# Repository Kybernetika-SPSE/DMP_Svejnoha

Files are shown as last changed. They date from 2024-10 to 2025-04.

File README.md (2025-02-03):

# Stanice pro monitorování okolního prostředí

## Zadání
Cílem projektu je navrhnout a následně vyrobit stanici složenou z LED displeje a senzorů, které budou sledovat vybrané parametry okolního prostředí. Zařízení bude obsahovat multifunkční displej a na základě uživatelských pokynů zobrazovat data. 

## Vedoucí práce
Jiří Švihla

## Harmonogram práce
- [x]   Zhotovení zadání MP (23. 9.)
- [/zadání maturitní práce/](zadani/DMP_zadani_SVEJNOHA.pdf)
- [x]   Výběr potřebných komponentů, seznámení se s problematikou a možnostmi programování LED
displeje (31. 10.)
- [/dílčí vypracování říjen/](dilci_vypracovani/SVEJNOHA_RIJEN.pdf)
- [x]   Návrh a realizace estetického a funkčního designu zařízení (28. 11.)
- [x]   Hardwarového zapojení senzorů a napájení (19. 12.)
- [/dílčí vypracování prosinec+listopad/](dilci_vypracovani/SVEJNOHA_LISTOPAD_A_PROSINEC.pdf)
- [x]   Programování displeje, zajištění možností využití zobrazení dat a ornamentů na displeji (30. 1.)
- [/dílčí vypracování leden/](dilci_vypracovani/SVEJNOHA_LEDEN.pdf)
- [ ]   Kompletace zařízení a testování (27. 2.)
- [ ]   Zpracování dokumentace (24. 3.)

## Termín odevzdání
31. března 2025

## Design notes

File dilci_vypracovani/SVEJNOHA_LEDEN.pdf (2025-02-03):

## MAREK ŠVEJNOHA – DÍLČÍ VYPRACOVÁNÍ – LEDEN

V lednu již dorazila vyrobená deska plošných spojů, ihned jsem začal s naletováním všech senzorů a konektorů na PCB aby mohlo co nejdříve dojít k programování.

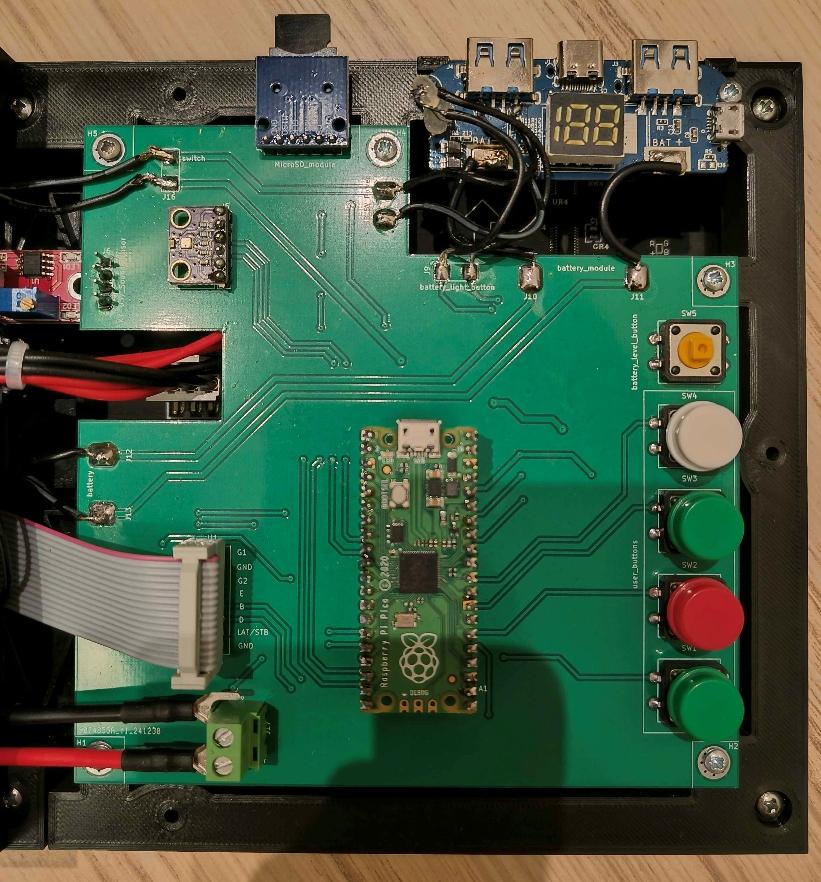
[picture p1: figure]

Postupně došlo k tisknutí dalších částí na 3D tiskárně.

V současné době dochází k programování. Zde přikládám návrh, jak bude již naprogramovaný displej vypadat:

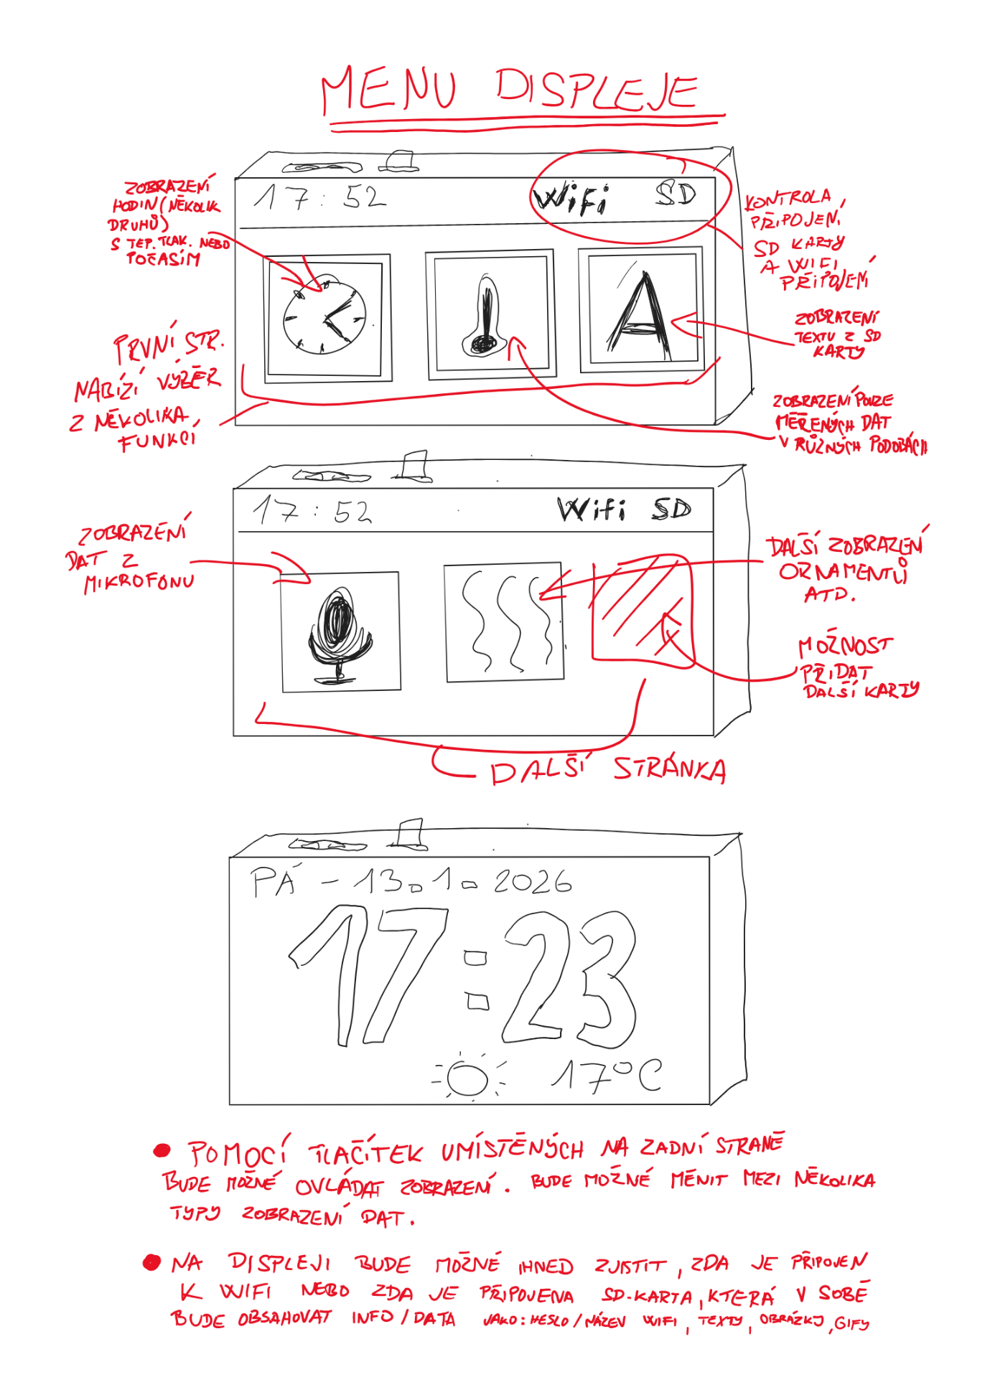
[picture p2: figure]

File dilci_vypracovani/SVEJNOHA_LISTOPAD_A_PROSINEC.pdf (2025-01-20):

MAREK ŠVEJNOHA – DÍLČÍ VYPRACOVÁNÍ – PROSINEC

Za prosincové období byl vypracován návrh desky plošných spojů (viz obrázek 1) v programu KiCad. Toto PCB bude obsluhovat displej. Je zde prostor pro mikrokontroler Raspberry pi Pico W, tlačítka nebo konektory. Bylo vypracováno hned několik nových footprintů a symbolů, které v knihovnách KiCadu nejsou, ale jsou pro tuto práci důležité. Například pro konektor HUB75 nebo pro konektorové lišty pro připojení senzorů. HUB75 je v návrhu připojen k Picu.

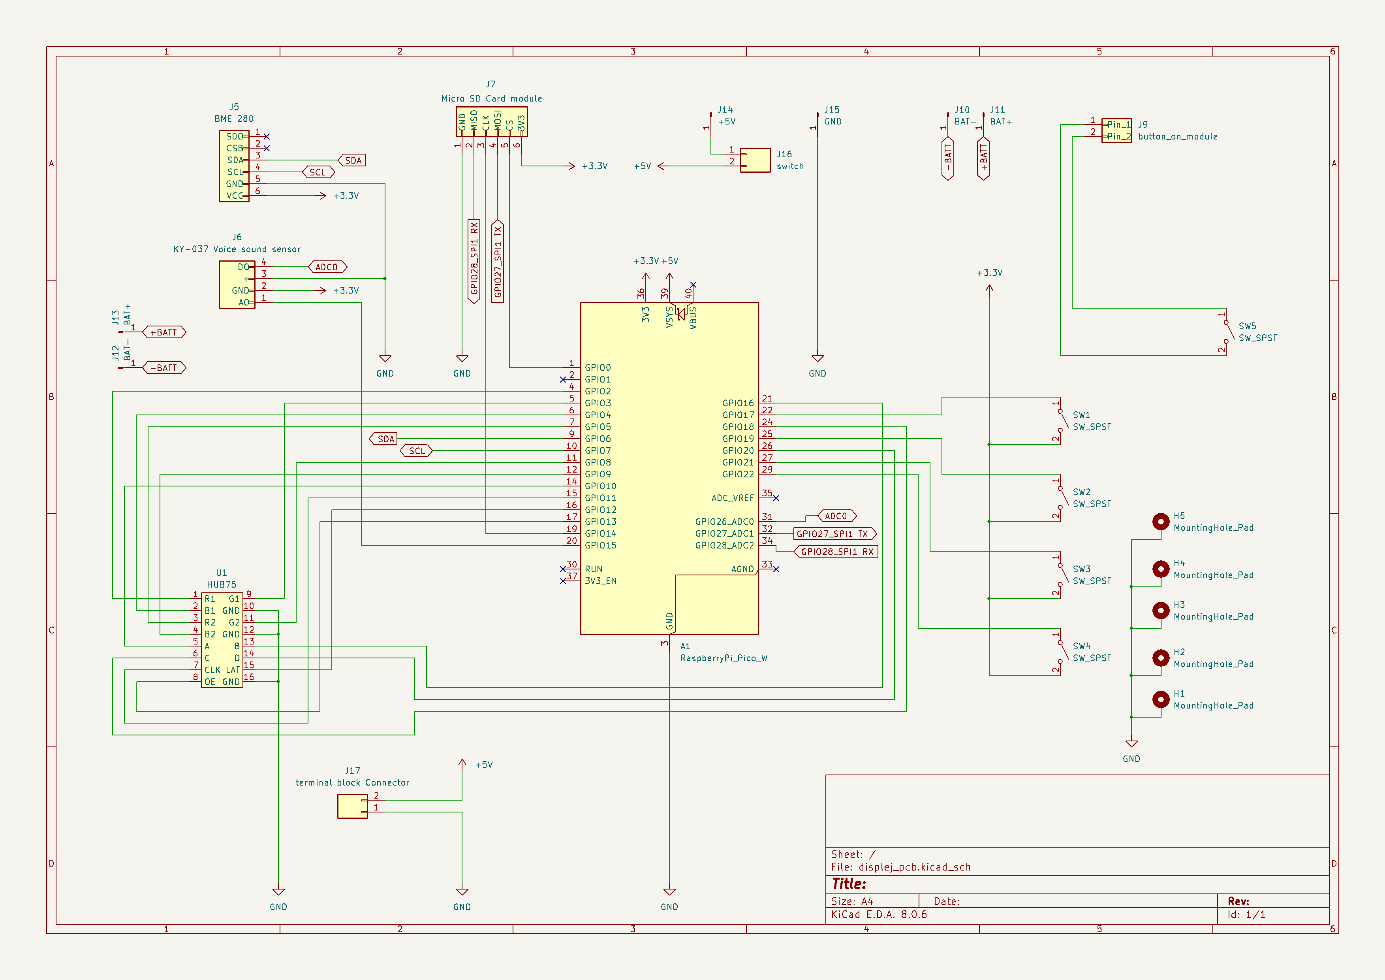
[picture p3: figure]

Obrázek 1

Napájení bude zajištěno pomocí nabíjecího modulu, který jsem získal z powerbanky, ten bude umístěn v pravém horním rohu, kde je pro něj připraven výřez (viz obrázek 2). Z modulu povedou kabely na desku. Za prvé to bude 5V napájení, které bude přivedeno z USB portu. Za druhé přívod k akumulátoru, který bude na druhé půlce displeje a za třetí bude vyvedené tlačítko pro ověření nabití baterie.

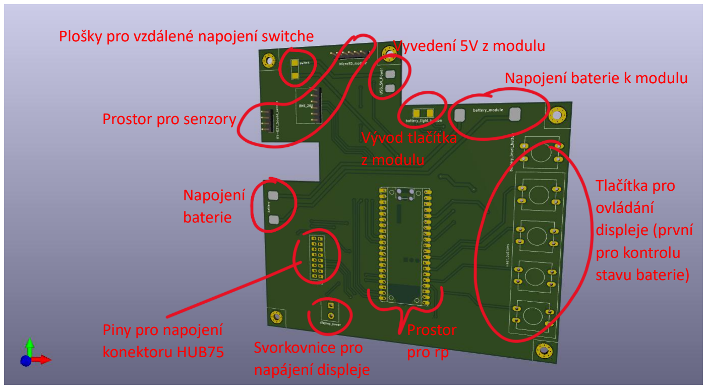
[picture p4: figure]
Napojení baterie k modulu; Vyvedení 5V z modulu; Vývod tlačítka z modulu; Napojení baterie; Plošky pro vzdálené napojení switche; Prostor pro senzory; Tlačítka pro ovládání displeje (první pro kontrolu stavu baterie); Prostor pro rp; Piny pro napojení; konektoru HUB75; Svorkovnice pro; napájení displeje

Vyvedených 5V pokračuje do hlavního spínače, které bude umístěno mimo PCB. To zajistí odpojení a připojení napájení k Picu a displeji. PCB obsahuje také 4 tlačítka pro ovládání displeje. Nakonec jsou zde díry pro uchycení k obalu displeje. Zbytek částí popsáno na obrázku (viz obrázek 2).

Obrázek 2

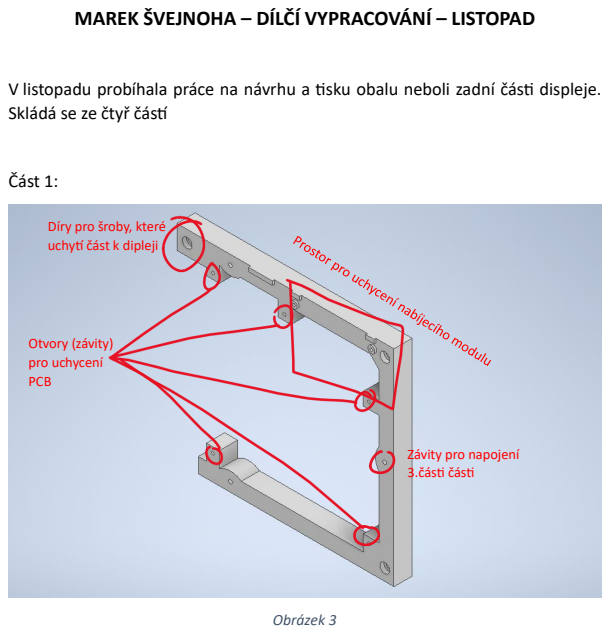
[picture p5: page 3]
Část 1:; Obrázek 3; Otvory (závity) pro uchycení PCB

MAREK ŠVEJNOHA – DÍLČÍ VYPRACOVÁNÍ – LISTOPAD

V listopadu probíhala práce na návrhu a tisku obalu neboli zadní části displeje.
Skládá se ze čtyř částí

Díry pro šroby, které
uchytí část k dipleji

Závity pro napojení
3.části části

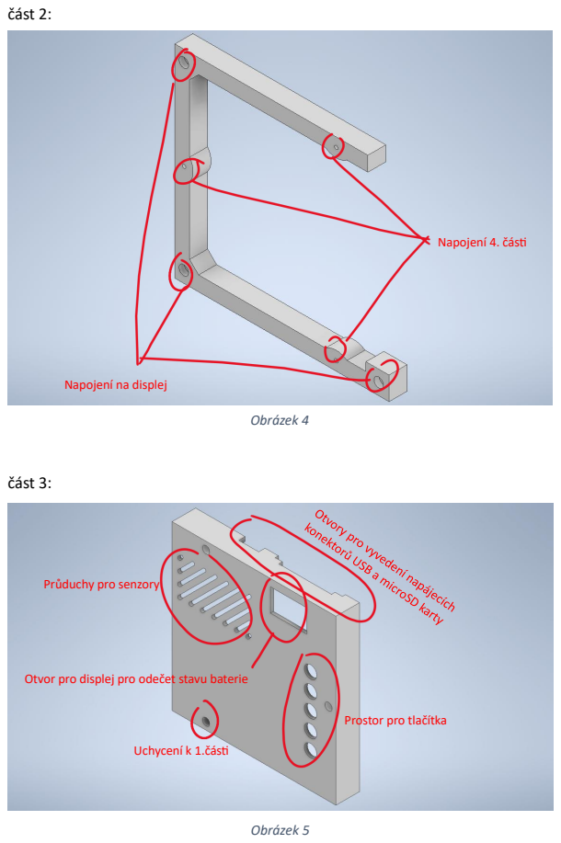
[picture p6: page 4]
část 2:; část 3:; Obrázek 5; Napojení 4. části; Uchycení k 1.části; Obrázek 4

Napojení na displej

Průduchy pro senzory

Otvor pro displej pro odečet stavu baterie

Prostor pro tlačítka

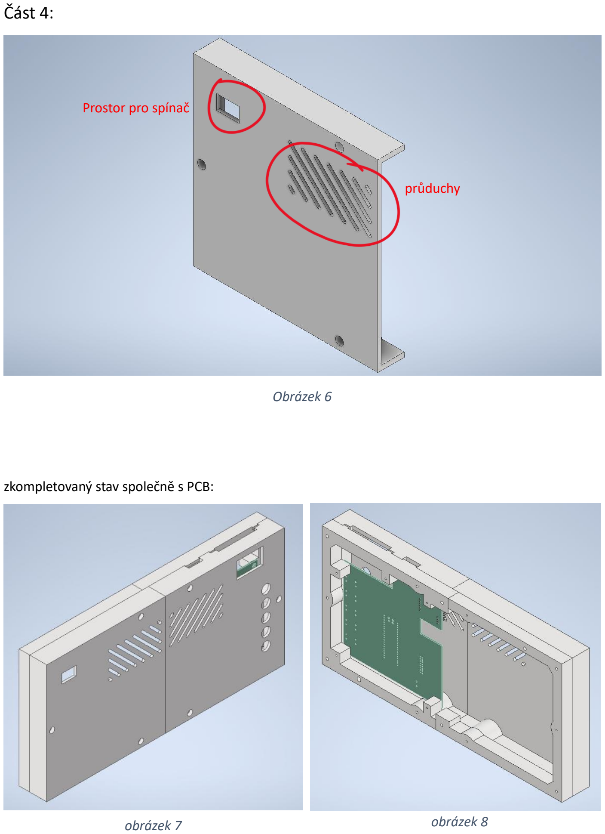
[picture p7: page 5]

Část 4:

Obrázek 6

zkompletovaný stav společně s PCB:

obrázek 7

obrázek 8

průduchy

Prostor pro spínač

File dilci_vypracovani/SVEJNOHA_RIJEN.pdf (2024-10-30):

MAREK ŠVEJNOHA – DÍLČÍ VYPRACOVÁNÍ – ŘÍJEN

V průběhu října jsem vybral komponenty, které jsou potřeba pro úspěšné sestavení výrobku. V první řadě byl objednán (23. října, 2024) Waveshare RGB plnobarevný LED maticový displej, 64 x 32 pixelů, který je ze všeho nejvíce důležitý. Displej podporuje ovládání pomocí Arduina, ESP32, Raspberry Pi nebo Raspberry Pi Pico, které pro ovládání využiji já. Displej vyžaduje samostatný napájecí zdroj 5 V/2,5 A. Použiji akumulátory a napájecí modul, což zajistí, že stanice bude jednoduše přemisťovatelná. Displej využívá rozhraní HUB75, které umožňuje ovládání přímo z řídící jednotky (Raspberry Pi Pico). Mimo jiné zahrnuje piny pro:

- Data: Přenos dat pro jednotlivé barvy (červená, zelená, modrá).
- Hodiny: Synchronizace přenosu dat.
- Latch: Ukládání dat do registrů.
- Enable: Povolení nebo zakázání displeje.
- Řádky: Výběr konkrétního řádku na displeji.

Jakmile displej dorazí, pustím se do programování a zapojení obvodu. Pro programování displeje je volně dostupná knihovna rpi-rgb-led-matrix. Tato knihovna je určena pro Raspberry Pi a umožňuje ovládání různých LED maticových displejů přes rozhraní HUB75. Je možné ji najít na GitHubu. Byl také zakoupen senzor DHT11 pro měření teploty a vlhkosti vzduchu a také zvukový senzor s analogovým výstupem, který využiji pro zobrazení zvuku na displeji. Další senzory budou popřípadě v budoucnu dokoupeny.

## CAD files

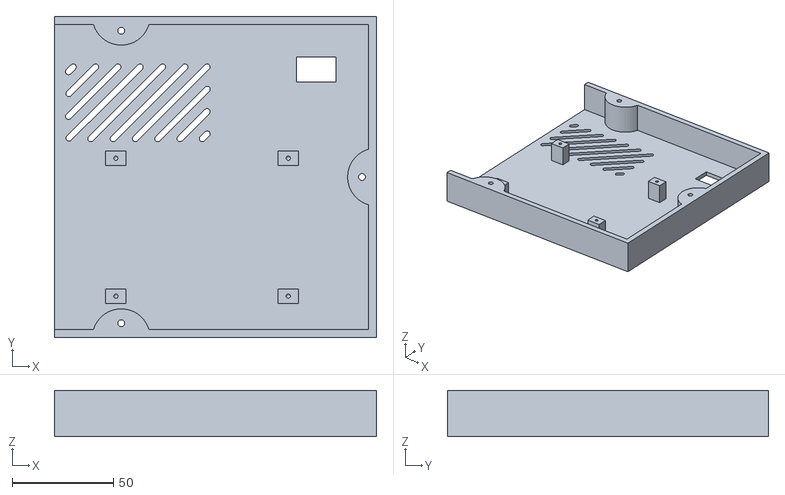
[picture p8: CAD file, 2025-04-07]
3D_modely/stl/display_cover_part2_back.stl
158.8 x 158.5 x 22.8

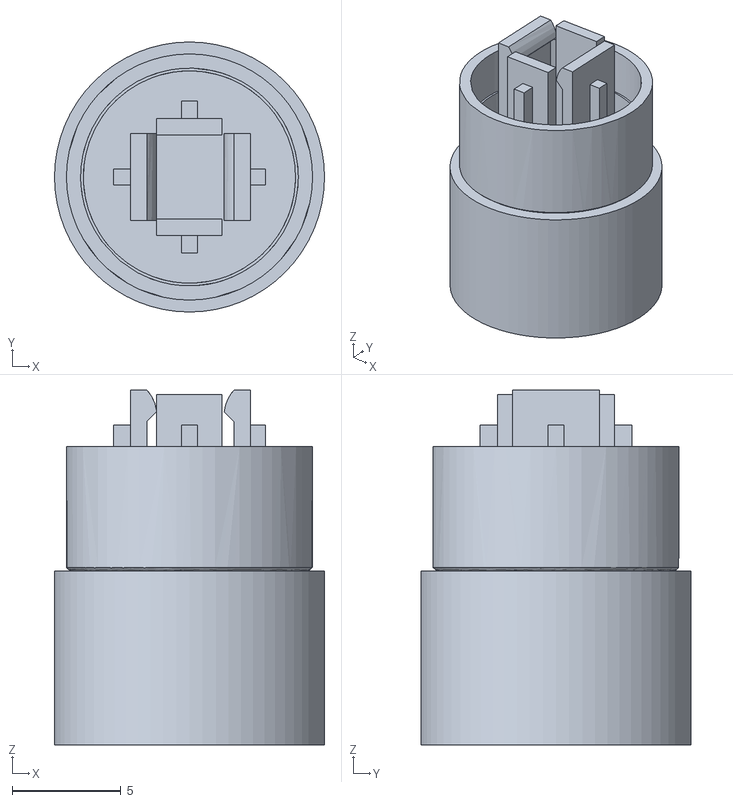
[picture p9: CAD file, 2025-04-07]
3D_modely/stl/setting_buttons.stl
12.4 x 12.4 x 16.3

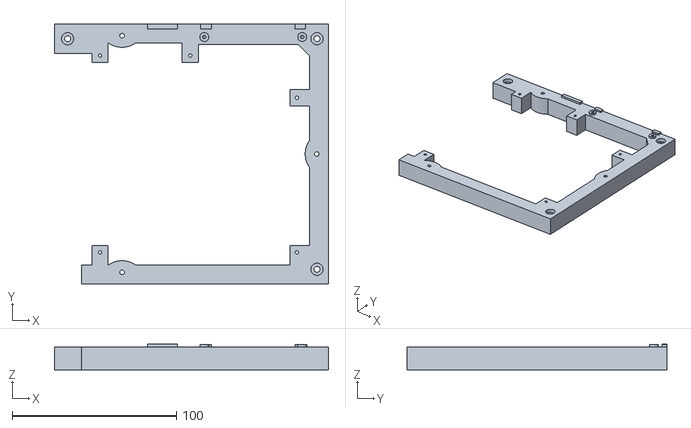
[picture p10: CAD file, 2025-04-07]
3D_modely/stl/display_cover_part1.stl
167.0 x 158.5 x 15.6

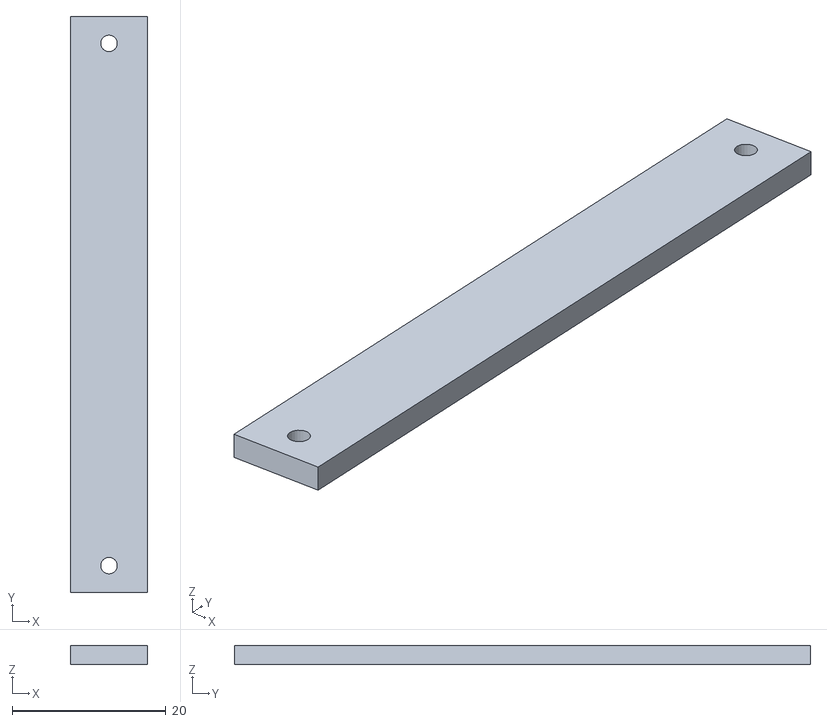
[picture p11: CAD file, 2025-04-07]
3D_modely/stl/battery_plate.stl
10.0 x 75.0 x 2.50

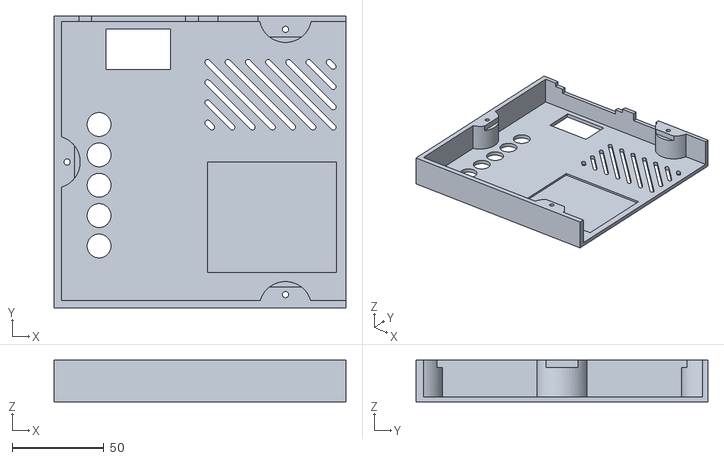
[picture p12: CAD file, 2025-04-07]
3D_modely/stl/display_cover_part1_back.stl
158.8 x 158.5 x 22.8

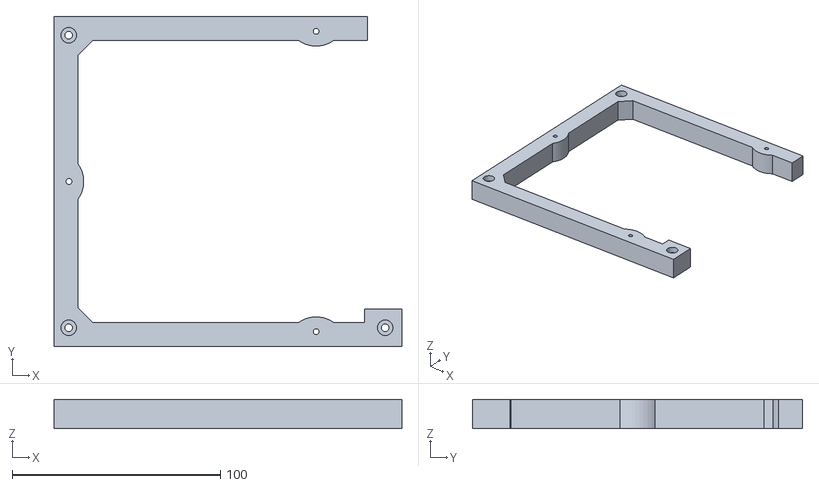
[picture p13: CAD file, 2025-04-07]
3D_modely/stl/display_cover_part2.stl
167.0 x 158.5 x 14.0

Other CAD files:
3D_modely/Sestava_kryt_na_displej_PCB.iam
3D_modely/battery_plate.ipt
3D_modely/button_plate_arrow.ipt
3D_modely/button_plate_battery.ipt
3D_modely/button_plate_brightness.ipt
3D_modely/button_plate_cross.ipt
3D_modely/display_cover_part1.ipt
3D_modely/display_cover_part1_back.ipt
3D_modely/display_cover_part2.ipt
3D_modely/display_cover_part2_back.ipt

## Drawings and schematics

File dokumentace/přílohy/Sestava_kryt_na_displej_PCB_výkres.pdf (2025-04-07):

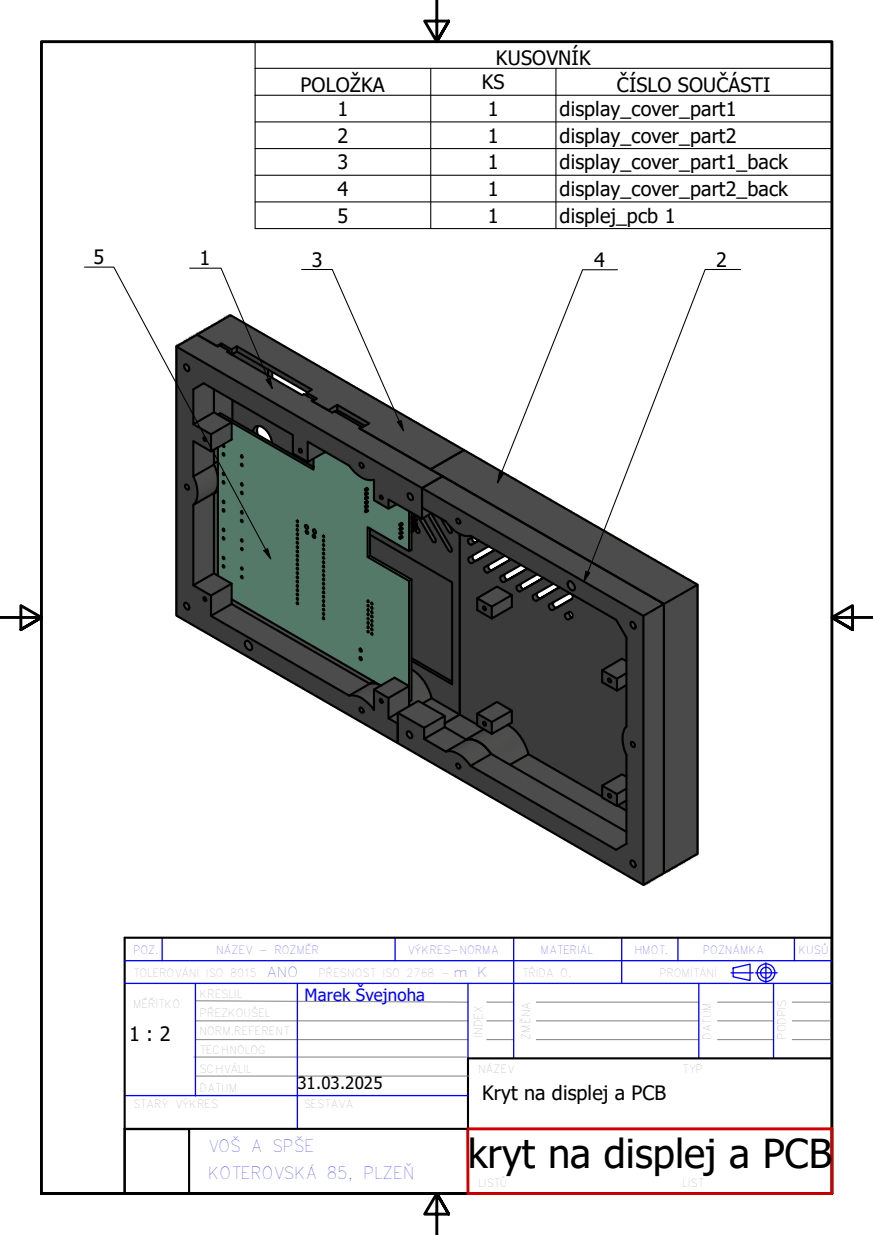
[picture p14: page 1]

KUSOVNÍK

POLOŽKA | KS | ČÍSLO SOUČÁSTI
1 | 1 | display_cover_part1
2 | 1 | display_cover_part2
3 | 1 | display_cover_part1_back
4 | 1 | display_cover_part2_back
5 | 1 | displej_pcb 1

POZ. | NÁZEV - ROZMĚR | VÝKRES-NORMA | MATERIÁL | HMOT. | POZNÁMKA | KUSŮ

TOLEROVÁNÍ ISO 8015 ANO PŘESNOST ISO 2768 -m K | TŘÍDA O. | PROMÍTÁNÍ
MĚŘÍTKO 1 : 2 | KRESLIL | Marek Švejnoha

PŘEZKOUŠEL

NORM.REFERENT
TECHNOLOG
SCHVÁLIL | | NÁZEV TYP Kryt na displej a PCB
DATUM | 31.03.2025

STARÝ VÝKRES | | SESTAVA

VOŠ A SPŠE KOTEROVSKÁ 85, PLZEŇ | kryt na displej a PCB LISTŮ LIST

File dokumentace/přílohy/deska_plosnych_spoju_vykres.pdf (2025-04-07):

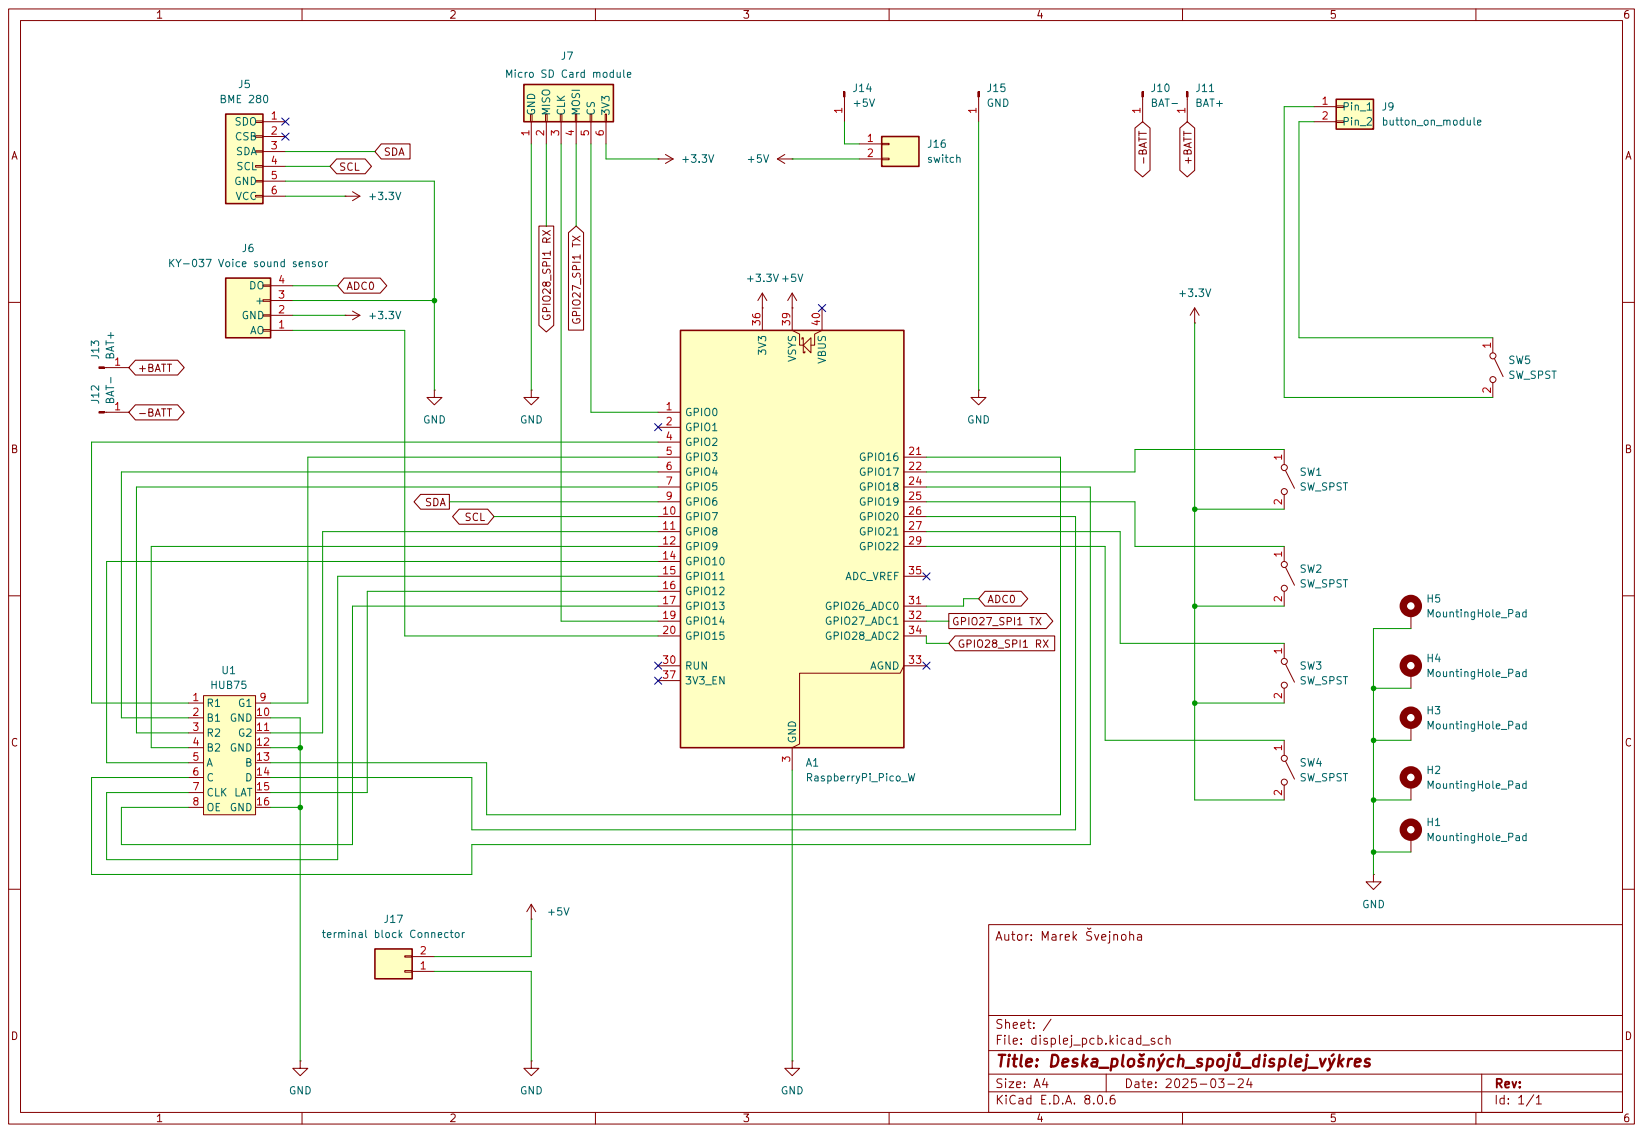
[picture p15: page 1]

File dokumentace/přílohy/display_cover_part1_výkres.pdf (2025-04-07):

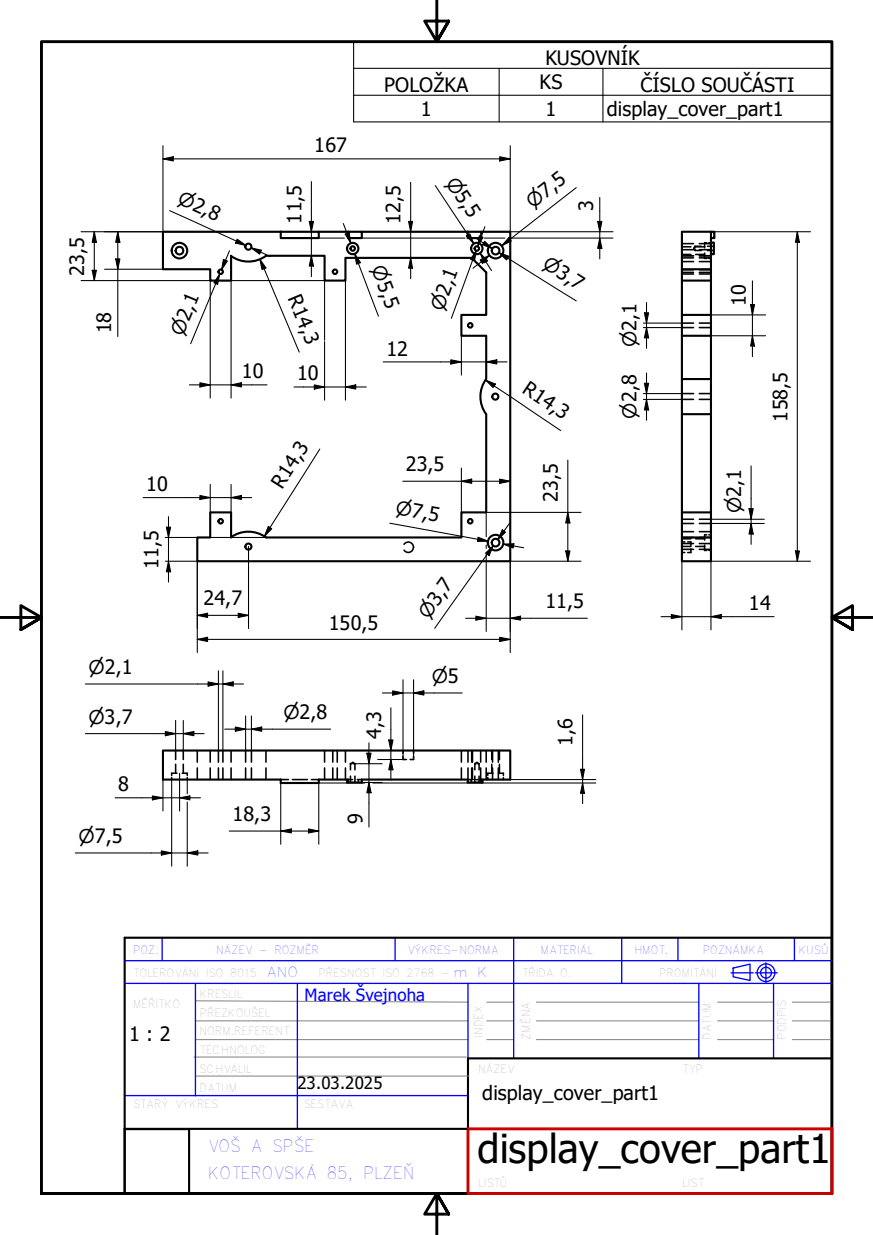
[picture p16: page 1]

KUSOVNÍK

POLOŽKA | KS | ČÍSLO SOUČÁSTI
1 | 1 | display_cover_part1

POZ. | NÁZEV - ROZMĚR | VÝKRES-NORMA | MATERIÁL | HMOT. | POZNÁMKA | KUSŮ

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

PŘEZKOUŠEL

NORM.REFERENT
TECHNOLOG
SCHVÁLIL | | NÁZEV TYP display_cover_part1
DATUM | 23.03.2025

STARÝ VÝKRES | | SESTAVA

VOŠ A SPŠE KOTEROVSKÁ 85, PLZEŇ | display_cover_part1 LISTŮ LIST

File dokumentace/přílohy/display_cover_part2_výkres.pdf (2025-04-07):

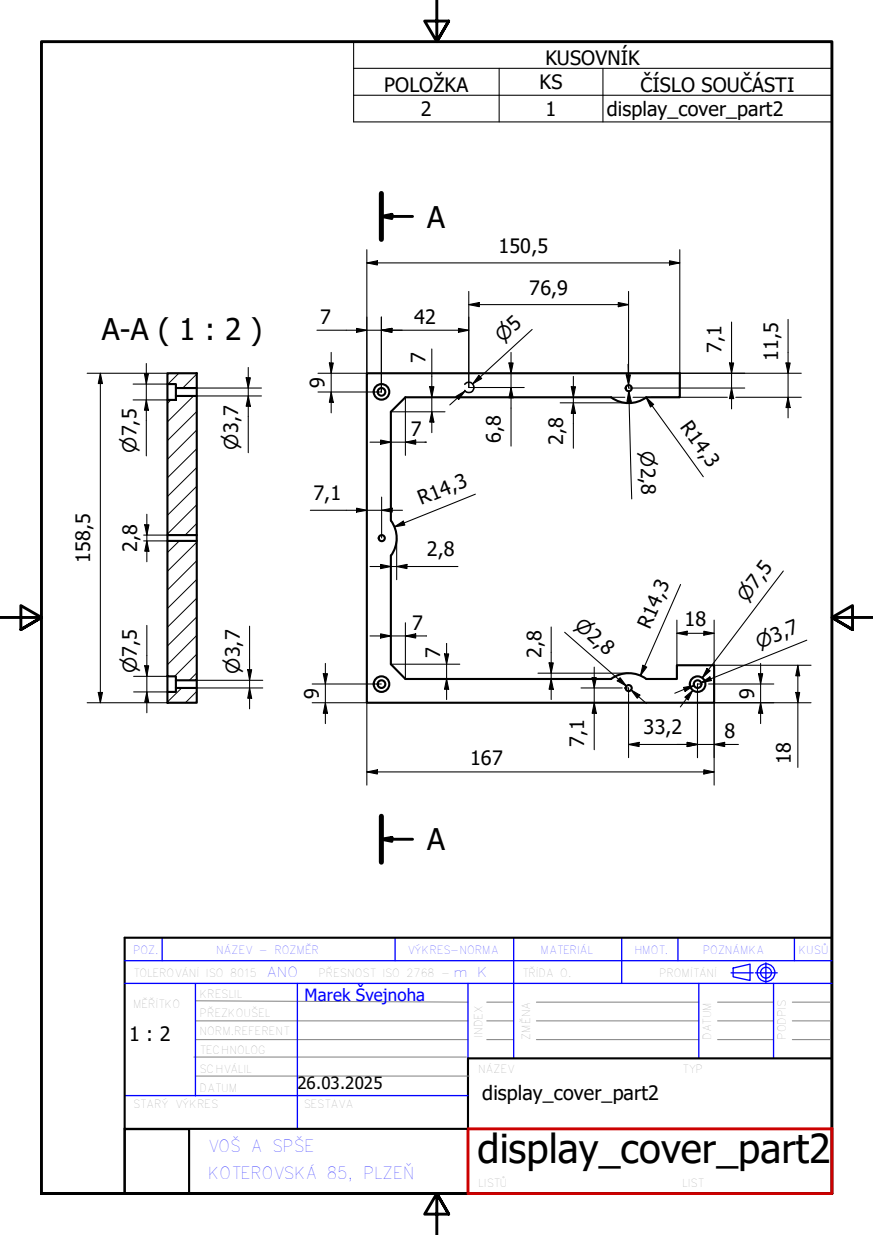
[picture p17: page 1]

KUSOVNÍK

POLOŽKA | KS | ČÍSLO SOUČÁSTI
2 | 1 | display_cover_part2

POZ. | NÁZEV - ROZMĚR | VÝKRES-NORMA | MATERIÁL | HMOT. | POZNÁMKA | KUSŮ

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

PŘEZKOUŠEL

NORM.REFERENT
TECHNOLOG
SCHVÁLIL | | NÁZEV TYP display_cover_part2
DATUM | 26.03.2025

STARÝ VÝKRES | | SESTAVA

VOŠ A SPŠE KOTEROVSKÁ 85, PLZEŇ | display_cover_part2 LISTŮ LIST

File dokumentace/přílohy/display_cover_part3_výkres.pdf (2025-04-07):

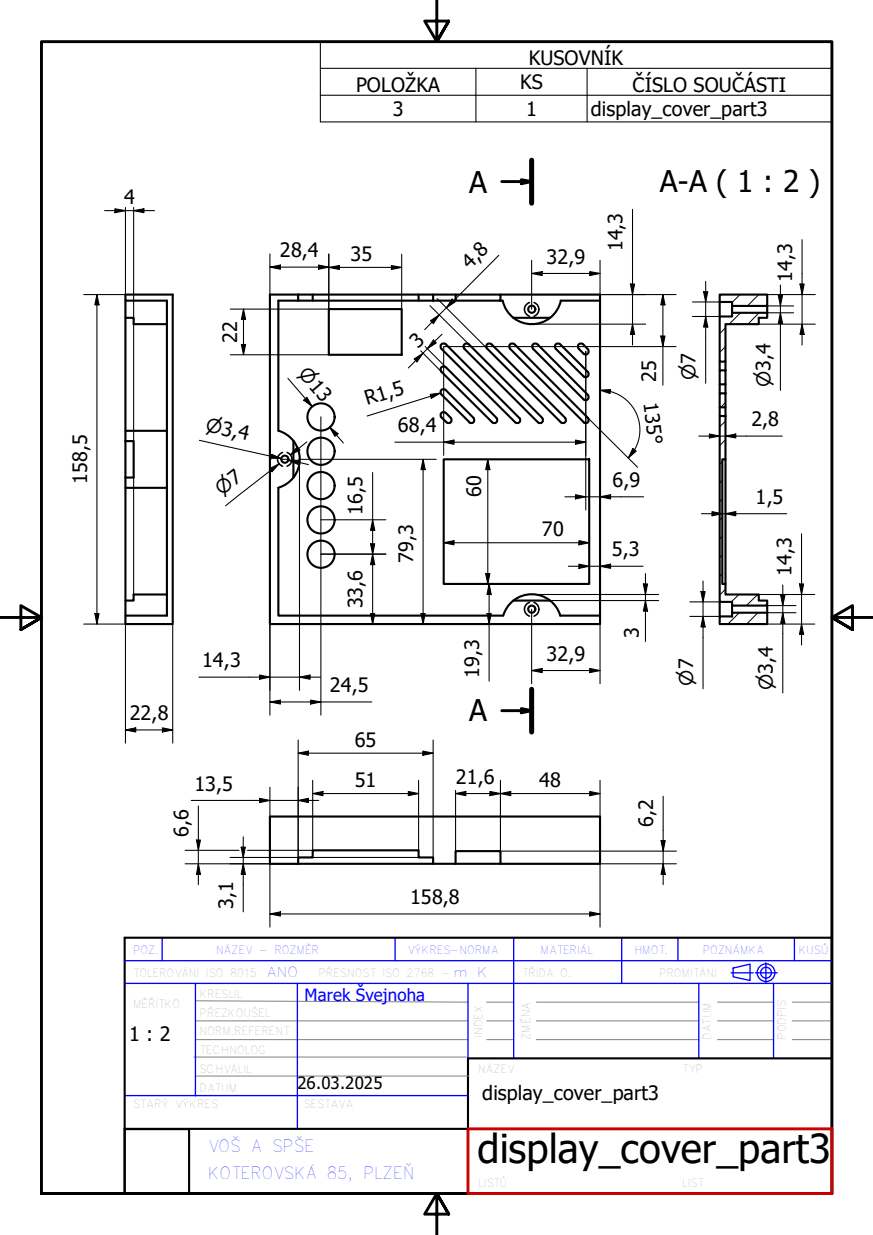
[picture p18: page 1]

KUSOVNÍK

POLOŽKA | KS | ČÍSLO SOUČÁSTI
3 | 1 | display_cover_part3

POZ. | NÁZEV - ROZMĚR | VÝKRES-NORMA | MATERIÁL | HMOT. | POZNÁMKA | KUSŮ

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

PŘEZKOUŠEL

NORM.REFERENT
TECHNOLOG
SCHVÁLIL | | NÁZEV TYP display_cover_part3
DATUM | 26.03.2025

STARÝ VÝKRES | | SESTAVA

VOŠ A SPŠE KOTEROVSKÁ 85, PLZEŇ | display_cover_part3 LISTŮ LIST

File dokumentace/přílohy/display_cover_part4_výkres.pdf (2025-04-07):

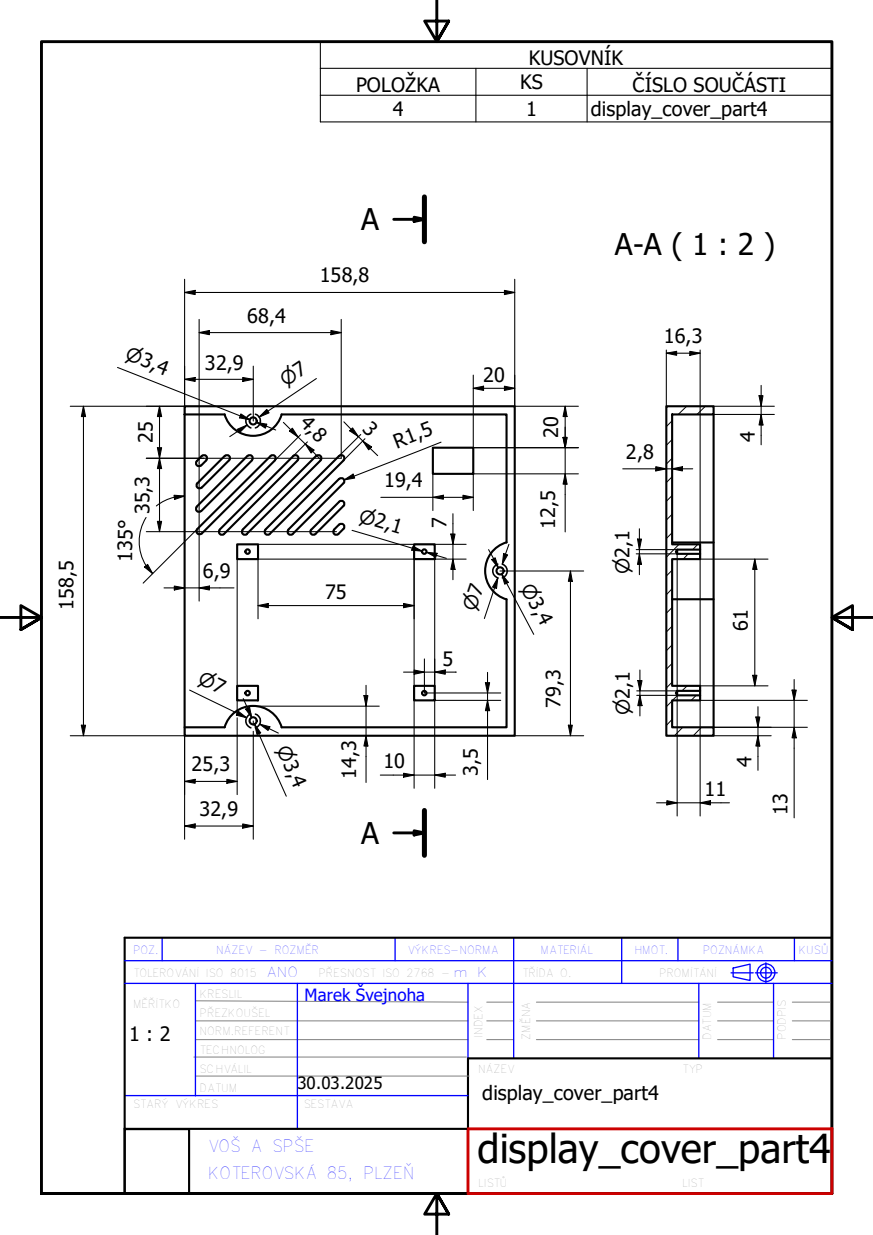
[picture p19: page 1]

KUSOVNÍK

POLOŽKA | KS | ČÍSLO SOUČÁSTI
4 | 1 | display_cover_part4

POZ. | NÁZEV - ROZMĚR | VÝKRES-NORMA | MATERIÁL | HMOT. | POZNÁMKA | KUSŮ

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

PŘEZKOUŠEL

NORM.REFERENT
TECHNOLOG
SCHVÁLIL | | NÁZEV TYP display_cover_part4
DATUM | 30.03.2025

STARÝ VÝKRES | | SESTAVA

VOŠ A SPŠE KOTEROVSKÁ 85, PLZEŇ | display_cover_part4 LISTŮ LIST

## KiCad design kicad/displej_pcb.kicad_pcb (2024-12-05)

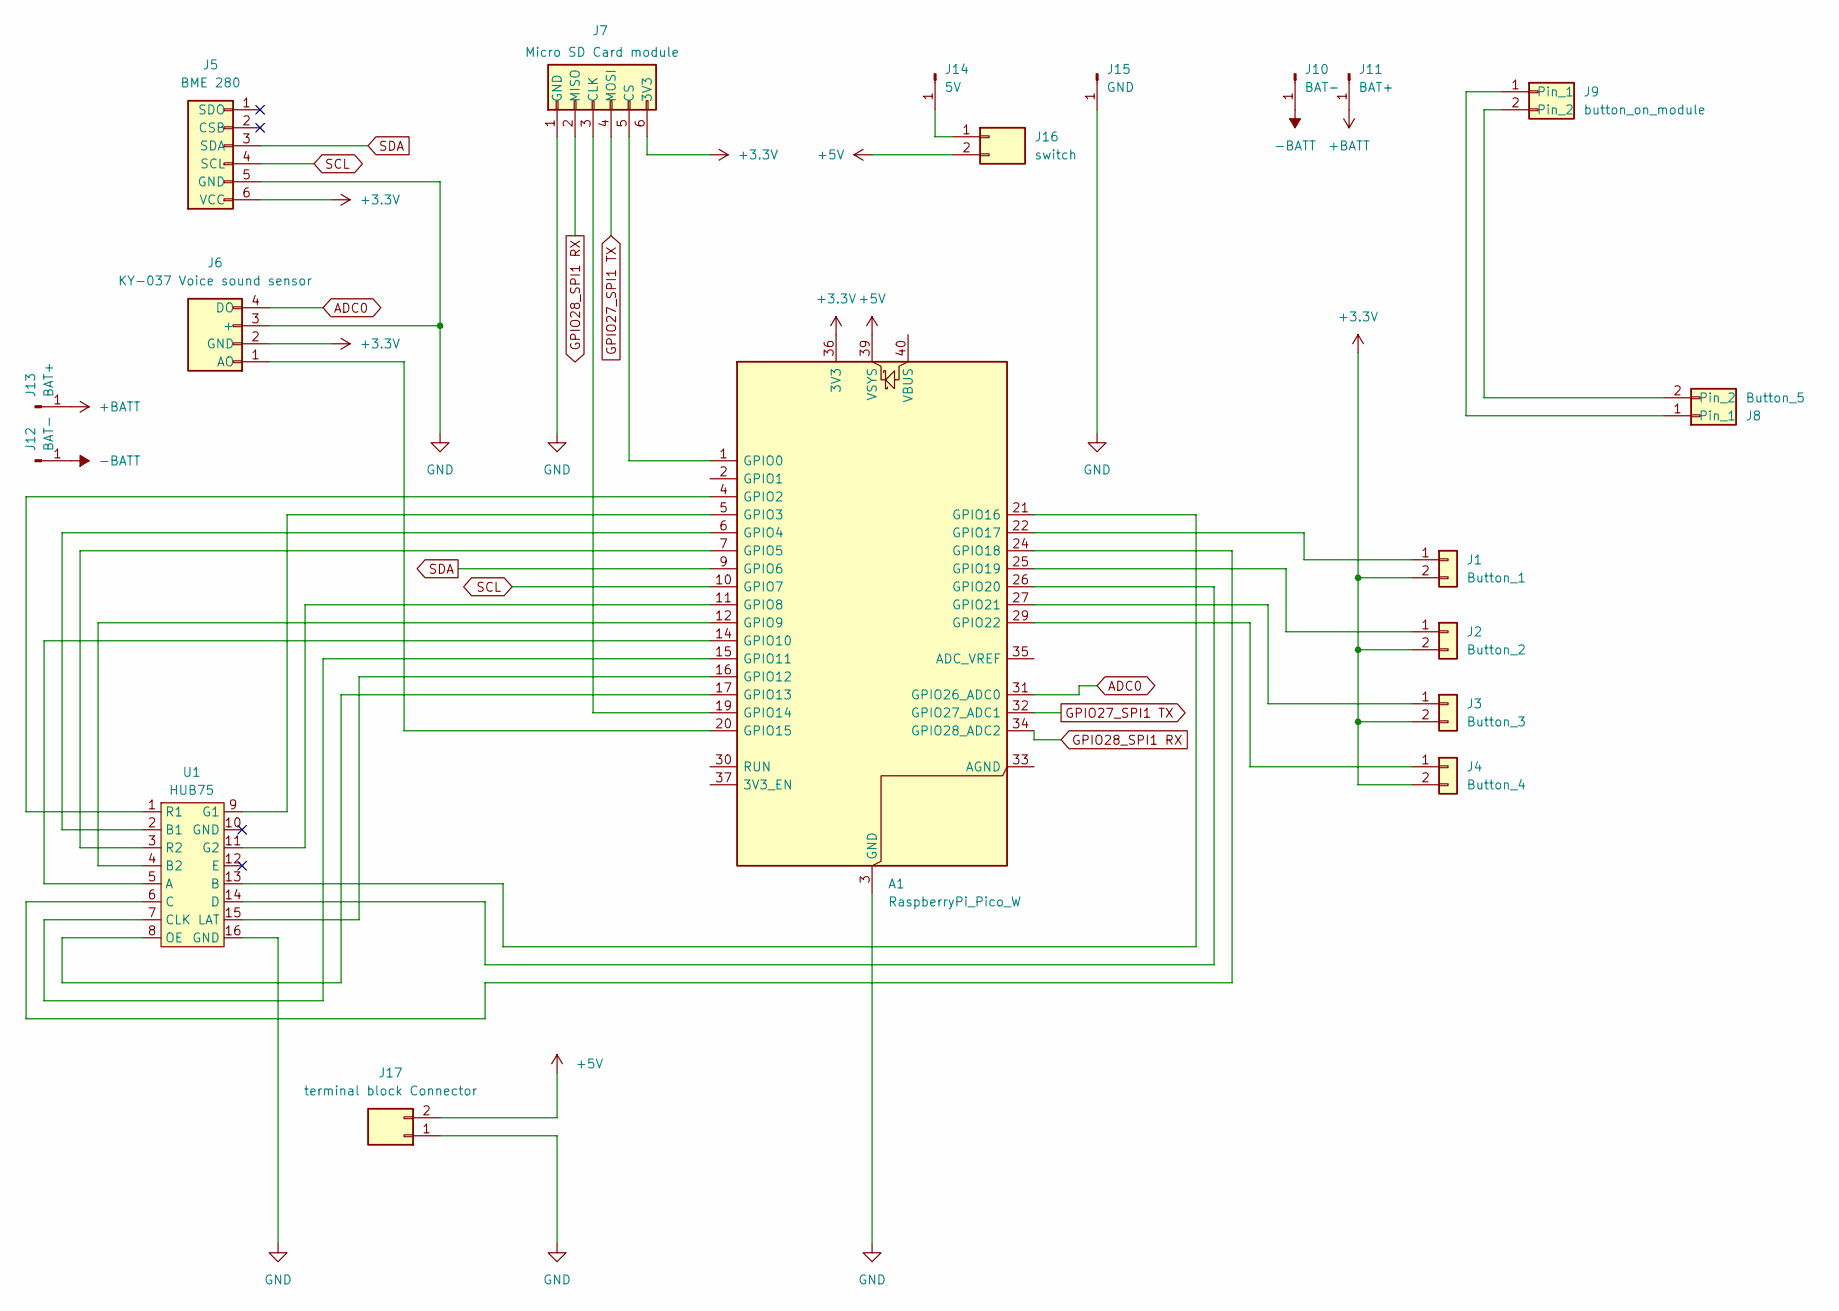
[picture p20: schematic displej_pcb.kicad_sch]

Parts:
A1: RaspberryPi_Pico_W; RaspberryPi_Pico_Common
J1: Button_1; buttons_solder_pins
J2: Button_2; buttons_solder_pins
J3: Button_3; buttons_solder_pins
J4: Button_4; buttons_solder_pins
J5: BME 280; PinHeader_1x06_P2.54mm_Vertical
J6: KY-037 Voice sound sensor; PinHeader_1x04_P2.54mm_Vertical
J7: Micro SD Card module; PinHeader_1x06_P2.54mm_Vertical
J8: Button_5; buttons_solder_pins
J9: button_on_module; solder_pads_2
J10, J12: BAT-; SolderWirePad_big
J11, J13: BAT+; SolderWirePad_big
J14: 5V; SolderWirePad_1x01_SMD_1x2mm
J15: GND; SolderWirePad_1x01_SMD_1x2mm
J16: switch; solder_pads_2
J17: terminal block Connector; JST_NV_B02P-NV_1x02_P5.00mm_Vertical
U1: HUB75; hub75

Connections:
+3.3V: A1.36 (3V3), J1.2, J2.2, J3.2, J4.2, J5.6 (VCC), J6.2 (GND), J7.6 (3V3)
+5V: A1.39 (VSYS), J16.2, J17.2
+BATT: J11.1, J13.1
-BATT: J10.1, J12.1
ADC0: A1.31 (GPIO26_ADC0), J6.4 (DO)
GND: A1.3 (GND), A1.8 (GND), A1.13 (GND), A1.18 (GND), A1.23 (GND), A1.28 (GND), A1.38 (GND), J5.5 (GND), J6.3 (+), J7.1 (GND), J15.1, J17.1, U1.16 (GND)
GPIO27_SPI1 TX: A1.32 (GPIO27_ADC1), J7.4 (MOSI)
GPIO28_SPI1 RX: A1.34 (GPIO28_ADC2), J7.2 (MISO)
unnamed: A1.1 (GPIO0), J7.5 (CS)
unnamed: A1.4 (GPIO2), U1.1 (R1)
unnamed: A1.5 (GPIO3), U1.9 (G1)
unnamed: A1.6 (GPIO4), U1.2 (B1)
unnamed: A1.7 (GPIO5), U1.3 (R2)
unnamed: A1.11 (GPIO8), U1.11 (G2)
unnamed: A1.12 (GPIO9), U1.4 (B2)
unnamed: A1.14 (GPIO10), U1.5 (A)
unnamed: A1.15 (GPIO11), U1.7 (CLK)
unnamed: A1.16 (GPIO12), U1.15 (LAT)
unnamed: A1.17 (GPIO13), U1.8 (OE)
unnamed: A1.19 (GPIO14), J7.3 (CLK)
unnamed: A1.20 (GPIO15), J6.1 (AO)
unnamed: A1.21 (GPIO16), U1.13 (B)
unnamed: A1.22 (GPIO17), J1.1
unnamed: A1.24 (GPIO18), U1.6 (C)
unnamed: A1.25 (GPIO19), J2.1
unnamed: A1.26 (GPIO20), U1.14 (D)
unnamed: A1.27 (GPIO21), J3.1
unnamed: A1.29 (GPIO22), J4.1
unnamed: J8.1, J9.1
unnamed: J8.2, J9.2
unnamed: J14.1, J16.1
SCL: A1.10 (GPIO7), J5.4 (SCL)
SDA: A1.9 (GPIO6), J5.3 (SDA)

Board: 2 copper layers, 19 parts (0 on the bottom side), 33 nets, no tracks yet.
